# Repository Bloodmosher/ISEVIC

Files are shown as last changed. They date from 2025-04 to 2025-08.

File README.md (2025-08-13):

# ISEVIC - Integrated System for Enhancing VIC Output
### ISEVIC is an FPGA core for enabling digital video via HDMI on the C-64. It works by watching the bus on the cartridge port. It then translates those signals into a picture for display. It can run on multiple FPGA platforms including the Tang Nano 20K described here.

## Getting Started
- You'll need a Tang Nano 20K board with headers like [this](https://www.amazon.com/dp/B0C5XJV83K) flashed with the provided bitstream plus the ISEVIC carrier board for the C-64 cartridge slot (see below).
- **For correct operation, three additional wires must be run from the CPU (_CHAREN, _HIRAM, _LORAM on pins 27, 28, 29) to the carrier board.**
- Without them you'll see a correct picture upon boot, but most programs will inevitably write to IO space with a different memory configuration than the default which will result in incorrect interpretation of the signals. 
- Use Dupont wires like [these](https://www.amazon.com/dp/B07GCZV4BS) (make sure they are long enough to route outside the board), with IC mini grabbers like [these](https://www.amazon.com/dp/B08V1HFHRY) or similar.

### Watch the first "teaser" video here:
Watch the first "teaser" video (https://www.youtube.com/watch?v=a9VlOROTK9U)

### And then a more in-depth introductory video:
And then a more in-depth introductory video (https://www.youtube.com/watch?v=pUL5m-21Lx0)

### Supported Hardware
- PAL and NTSC "new" with automatic detection
- NTSC "old" and Drean machines are NOT supported at this time
- Core runs on the multiple FPGA devices
- Tang Nano 20K carrier board gerbers and bitstream are included in this repo
- **Reloaded MK2 motherboard is not currently supported**

### Display Devices
- Modern OLED monitors and TVs work really well. Game mode can also give an extra silky feel to scrolling images.
- My personal favorite monitor for the ISEVIC is the 32" LG 32GS95UE - it can handle the 1280x720 output of the Tang Nano 20K at both PAL and NTSC refresh rates, with no ghosting artifacts.
- Many IPS or TFT panels exhibit ghosting artifacts - your mileage will vary.

### What about sound?
While not part of the ISEVIC core itself, experimental support for sound by integrating SID emulation with the ISEVIC core is included in the provided bitstream. 

### Passthrough Port
Most cartridges should work via the passthrough port, however some are more sensitive to the additional path length and sharing of the signals. Examples that have been tested and seem to work well:
- 1541 Ultimate-II
- Backbit
- CMD Super CPU Rev 1A
- Epyx Fast Load
- Several simple game cartridges

The EasyFlash 3 is an example found to be more sensitive, e.g. some games failed to load in my testing. A future update may address this once fully understood.

### Tang Nano 20K Carrier
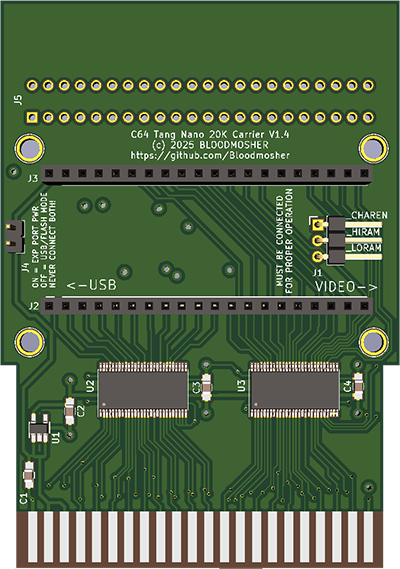
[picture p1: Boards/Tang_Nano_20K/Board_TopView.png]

- Gerbers for the Tang Nano 20K Carrier board can be found [here](./Boards/Tang_Nano_20K/Carrier/). 
- An optional [top plate](./Boards/Tang_Nano_20K/Top_Plate/) is also provided to help prevent touching the board during operation, and to mask the LEDs that activate due to the way signals are shared on the board.
- Always unplug the cartridge from your C-64 before updating the bitstream.
- The power select jumper on the Tang Nano 20K carrier board allows powering the device via USB but most users will have no need for this. 
- **Never connect USB with the jumper installed, you will send +5V into your C-64.**
- S1 and S2 buttons on the Tang Nano 20K provide access to the on-screen debug/calibration tool and reset of the C-64.
- **The BL616 firmware on your Tang Nano 20K most likely needs to be re-flashed to a supported version**, [follow the instructions here](./Docs/BL616_Firmware.md) before proceeding with the below.
- For updating the Isevic bitstream on Mac and Linux, use [OpenFPGALoader](https://github.com/trabucayre/openFPGALoader)
    - Mac users with [Homebrew](https://brew.sh/) can just type `brew install openfpgaloader` in the Terminal to install it
    - For updating using OpenFPGALoader:
        - Download the [isevic_tn20k_v1_0.fs](Boards/Tang_Nano_20K/Bitstream/isevic_tn20k_v1_0.fs) bitstream file by navigating to the link and then choosing *Download raw file*
        - Open the Mac Terminal or Linux shell and `cd` into the directory where you've saved the `isevic_tn20k_v1_0.fs` file
        - Make sure you've connected the Tang Nano 20K module via USC-C to your Mac or Linux computer
        - Run `openfpgaloader -b tangnano20k -f isevic_tn20k_v1_0.fs`

- For updating the bitstream on Windows, you will need the Gowin Education Edition IDE. 
    - [Windows](https://dl.sipeed.com/shareURL/TANG/gowin_ide) (also available for [Linux](https://dl.sipeed.com/shareURL/TANG/gowin_ide))
    - For updating the device using the Gowin Programmer from the above download:
        - Download the [isevic_tn20k_v1_0.fs](Boards/Tang_Nano_20K/Bitstream/isevic_tn20k_v1_0.fs) bitstream file by right-clicking on the link and choosing *Save Link As...*
        - Attach a USB cable from your PC to the Tang Nano 20K USB-C socket
        - Launch the Gowin Programmer. The *Cable Setup* dialog will appear and should detect the USB cable and the Tang Nano 20K device.  The FPGA will appear in the device list as *GW2AR-18C*.
        - If any device appears in the device list with anything other than *GW2AR-18C* then click on it and hit the *Delete Device* button.  If there no devices after doing this, click *Scan Device* and it will say *Multi-device found*, select *GW2AR-18C*.
        - Right click on the device and select *Configure Device*
        - Select *External Flash Mode*, choose *Generic Flash* in *External Flash Options*, leave address at *0x000000*. Select the `isevic_tn20k_v1_0.fs` file in *Programming Options File Name*. Hit *Save*.
        - Hit *Program/Configure*.  It will program the device.

### Clock Adjustment
For smooth scrolling the FPGA's pixel clock runs at a speed to match the Commodore 64's frame rate. It assumes the Commodore 64's clock is set to a standard specification.
If it is running too fast or too slow you'll see the screen flash periodically when it re-adjusts the clock sync. If tuned properly you should be able to run for many hours without ever seeing a sync loss occur.

- In order to tune the value you'll need an anti-static ceramic screwdriver, like [this one](https://www.amazon.com/Frequency-Screwdriver-Anti-static-Plastic-Ceramic/dp/B07GZHKH4B) or equivalent. A metal one will interfere with the signal.

- Locate the variable capacitor near the clock oscillator next to the VIC chip.
- To adjust the clock, press the S1 button on the FPGA to bring up the on screen calibration tool.
- The first number is the Commodore 64's clock speed. The measurement isn't perfect but is close enough.
- On the second row, the first three digits are the line number that the VIC is on at the top of the FPGA's video frame. The second three digits are the same thing but for the previous frame.
- When the clock is calibrated correctly the second number is always one higher than the first.
- You want the numbers to be changing as slowly as possible to avoid losing sync.
- The last two digits keeps a count of how many times sync loss has occurred.
- Make ultra tiny movements until you reach a value close to or a little under 985,248 for PAL at 50.1 hertz or 1,022,727 for 59.826 hertz NTSC. Watch the effect on the second row and make sure the line number is decreasing not increasing. The tuned value does not need to match these exactly and in fact on most setups I have found a little under works best.

### Tested Functionality
All supported C-64 video modes and most demo tricks have been tested on both PAL and NTSC machines. However, there is a massive library of software for the C-64 and inevitably there will be some display bugs. If you find an example, please open an issue and provide steps to reproduce. 

## Source Code
ISEVIC is written in Verilog and I intend to release the source code in a future update.

## Releases
### V1.0: Initial release
- Support for PAL/NTSC "new" VIC chips, NTSC "old" and Drean are explicitly disabled and will show a red screen
- Known Issues
    - The loading progress bar on Super Mario Bros incorrectly shows a leading black line as the bar moves from left to right.
    - When using the Easy Flash 3 in the pass through port, some programs fail to load.

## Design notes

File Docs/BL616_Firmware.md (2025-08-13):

# Tang Nano 20K BL616 Firmware
### ISEVIC currently requires that your Tang Nano 20K boared has the 2023030621 version of the BL616 firmware. If you bought your Tang Nano recently, most likely it has a newer firmware and will need to be re-flashed with the supported version.

If you do not have the correct version you may see noise like this in the picture:

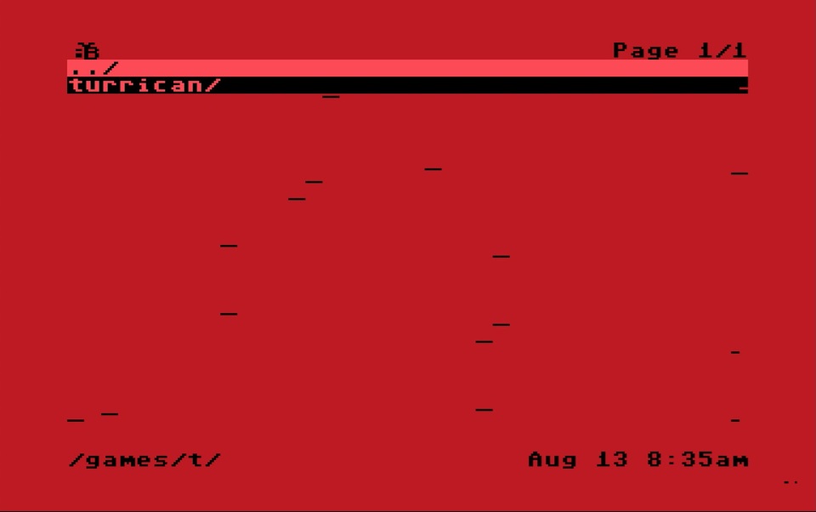
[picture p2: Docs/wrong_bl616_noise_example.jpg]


## Instructions
You'll need to first verify the version that is on your device, and if it is not 2023030621, re-flash the device.

### 1. Check the version
Unplug from your C64. On a Windows machine, plug the TN20K into your USB port, then open the Device Manager and look for "USB Serial Converter A/B" under "Universal Seerial Bus controllers", right click and select Properties, then go to the Details tab and choose the Parent Property as in the below:

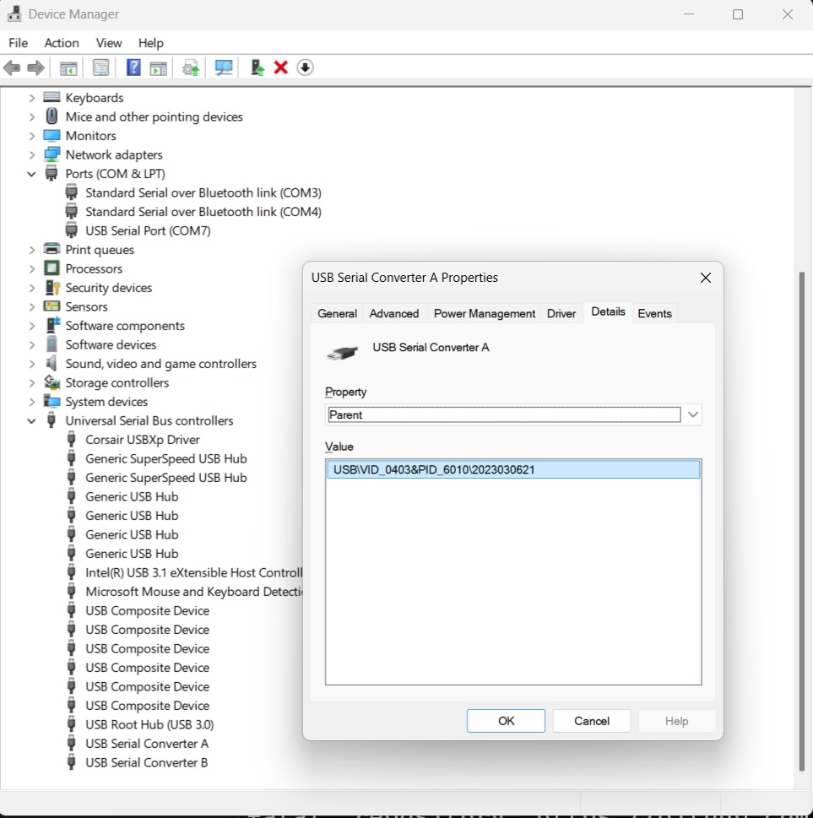
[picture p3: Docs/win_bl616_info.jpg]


If the version string is anything other than what is shown in the picture, proceed to the next step.

### 2. Download the tools and firmware
- You'll need to use the BLDevCube software which can be found [here](https://dl.sipeed.com/shareURL/SLogic/SLogic_combo_8/4_application/Tools)
- The correct version of the firmware is [here](../Boards/Tang_Nano_20K/Bitstream/bl616/bl616_2023030621.zip), navigate to the link and choose *Download raw file*, and then unzip the .zip file.

### 3. Re-flash the device
There is a detailed tutorial on how to re-flash the device [here](https://wiki.sipeed.com/hardware/en/tang/common-doc/update_debugger.html).

Basically,
1. Put the device into DFU mode by first unplugging from USB, then while holding the devices Update Button on the board, plug it back in. If you have the Isevic top plate you will need to remove it as the update button is hidden below the top plate and is located near the HDMI connector.
2. Start BLDevCube, select "BL616/618" as the chip model
3. In the new window, check the "Enable" checkbox below the "Single download option". Make sure the starting value near the enable button is 0x0.
4. Click Browse to locate the bl616_2023030621.bin file downloaded previously
5. Click "Create & Download" to flash to the device

### 4. Verify
1. Verify again from the Windows Device Manager that you have the correct version.
2. Unplug from USB.
3. If needed, finish the installation steps including flashing the Isevic bitstream as describe on the [main page](../README.md).
3. Plug back into your C64, you should now have a stable picture without the noise.

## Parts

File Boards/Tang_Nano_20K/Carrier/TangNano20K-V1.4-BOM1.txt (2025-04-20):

Comment	Designator	Footprint	JLCPCB Part #?optional?
CL21B105KBFNFNE (1uF)	"C1,C2"	C0805	C318709
C0805C104J1REC7210 (100nF)	"C3,C4,C5,C6"	C0805	C2215541
TLV74333PDBVR	U1	SOT-23-5	C408972
SN74CBTD16211DGGR	"U2,U3"	TSSOP-56_6.1x14mm_P0.5mm	C2674790
WingTAT S-44L-2.54-5	J5	"Edge Connector Plugin,P=2.54mm,44P"	C9900143422
2.54mm Spacing 20p Single row pin socket	"J2,J3"	2.54mm Spacing 20p Single row pin socket	C5439675
2.54mm Spacing 2p Single row pin header	J4	 2.54mm Spacing 2p Single row pin header	C2915055
2.54mm Spacing 3p Single row pin header Right Angle	J1	 2.54mm Spacing 3p Single row pin header Right Angle	C5517745
ABM8G-25.000MHZ-4Y-T3	Y1	SMD3225-4P	C596914
SI5351A-B-GTR	U4	MSOP10	C5451727
RT0805BRB0710KL	"R1,R2"	R0805	C864029

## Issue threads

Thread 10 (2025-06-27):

Feature request: Internal board version

jueank, 2025-06-27:
Hi Bloodmosher,
I just recently came across your project (thanks to Jan Beta’s video), and I have to say - it looks great! Thanks a lot for all the effort.

I had a quick look at the Gerber files for the carrier board—six copper layers. I wasn’t expecting that...

One thing I’d really love to see: for a more permanent setup, it would be great to have an internal version of the board. Maybe something that replaces the RF modulator - that seems like a logical spot. Do you think it would be possible to have this in combination with a small board at the cartridge port (possibly passing the port through), with a flex cable or ribbon cable connecting to the main board? If the main board were mounted in place of the RF modulator, you could run the three wires to the CPU much shorter or use a custom adapter, kind of like the one for the VIC in the HD64 project.

I was wondering if you'd consider releasing the board design files? Totally understand if you’d prefer to keep them private. On the other hand, I guess most of the “real magic” is probably in the FPGA gateware anyway. The PCB is clearly a lot of work, but ultimately just a means to an end, right? If you did share the files, others (myself included, potentially) could explore creating an internal version of the board that fits into the RF modulator space.

Thanks again for your awesome work - really looking forward to seeing where this goes!

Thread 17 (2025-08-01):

tang nano 9k

fanoush, 2025-08-01:
Hello,  is Tang Nano 9k   too small for your code or you simply had Nano 20k so you used that one but 9k would possibly work too?

Found this https://www.reddit.com/r/GowinFPGA/comments/1ltamqe/the_c64s_video_chip_vicii_on_the_tang_nano_9k/ , then had idea about putting this to cartridge, but after bit of googling I found you already did exactly that with 20k.

Bloodmosher, 2025-08-01:
The current design uses about 89% of the TN20K, so definitely doesn't fit on the 9K.

I had not heard of that project, thanks for sharing!

fanoush, 2025-08-01:
Oh, OK, thanks. I was first thinking that maybe 20k has more pins available for handling cartridge slot but then checked 9k pinout and that's probably not it as there is maybe even more pins available on 9k. So maybe it is the SID you have there too? That 9k project has VIC and RAM and also 6502 CPU there so maybe it is doable with 9k without SID. 9k is cheaper (maybe 1/2 of 20k).

Anyway, great project, thanks, even 20k is much cheaper than many current solutions and has space to fit more stuff there in future so it is good choice too, I hope you'll release the source eventually.
